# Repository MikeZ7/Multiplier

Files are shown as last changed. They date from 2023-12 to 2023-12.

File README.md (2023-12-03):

# Multiplier

Project of four quadrant multiplier for Systems and Electronics Circuits subject

---

## Project description
* Power Supply: (4V - 6V) DC
* Input signals range: (-1.5V - 1.5V) DC/AC
* PCB dimensions: 60x30mm 
* PCB components size: 0805
  
---

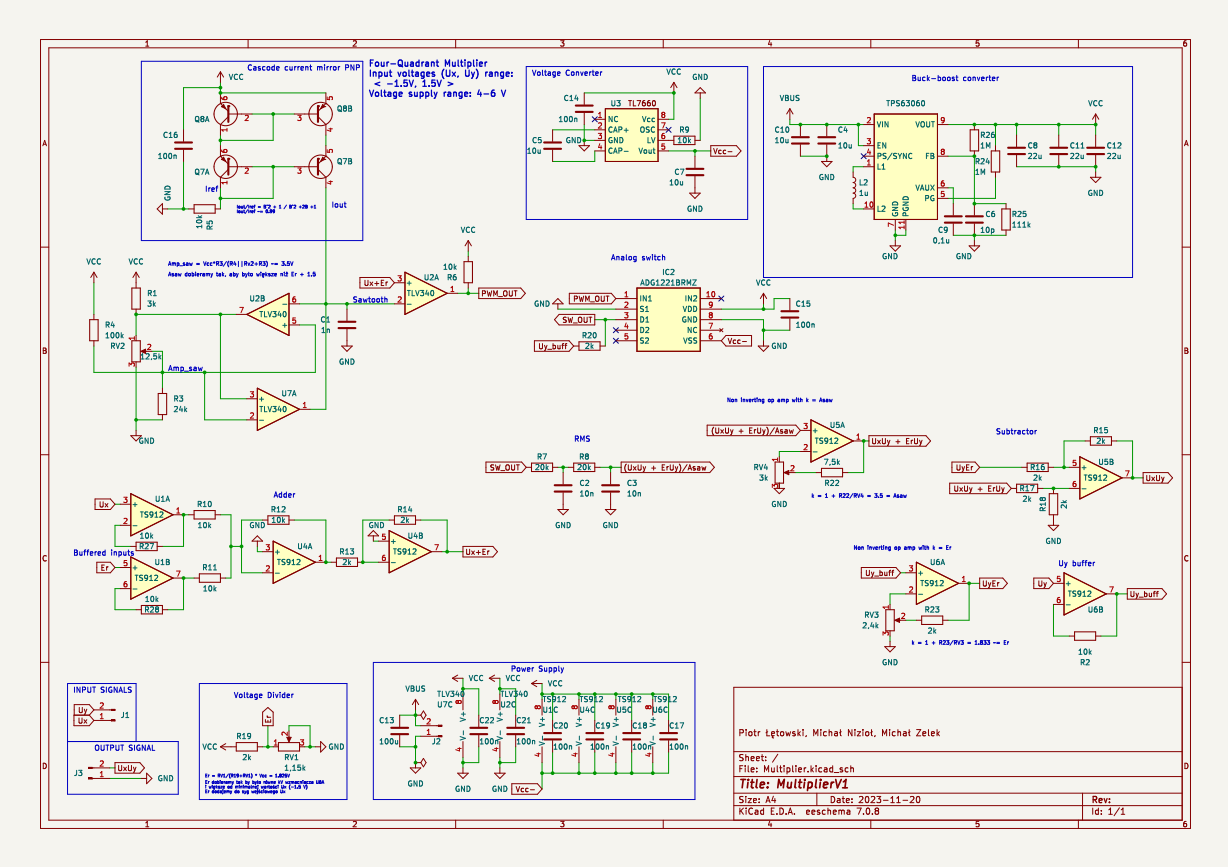
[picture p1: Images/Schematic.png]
Schematic


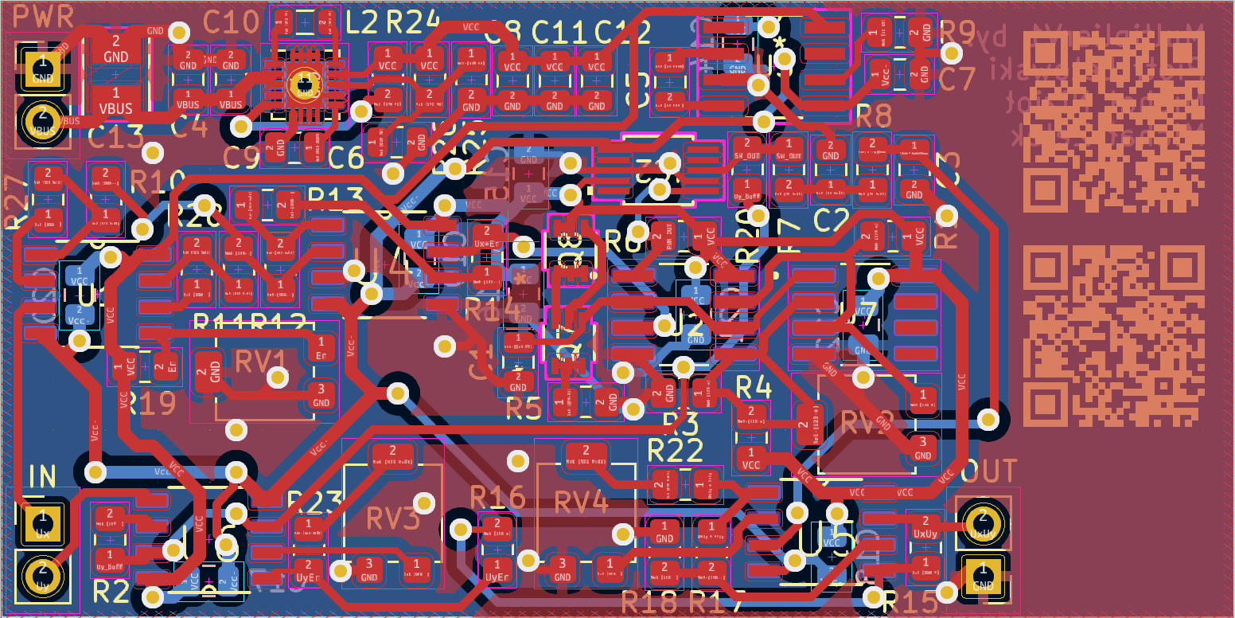
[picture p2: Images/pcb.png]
PCB


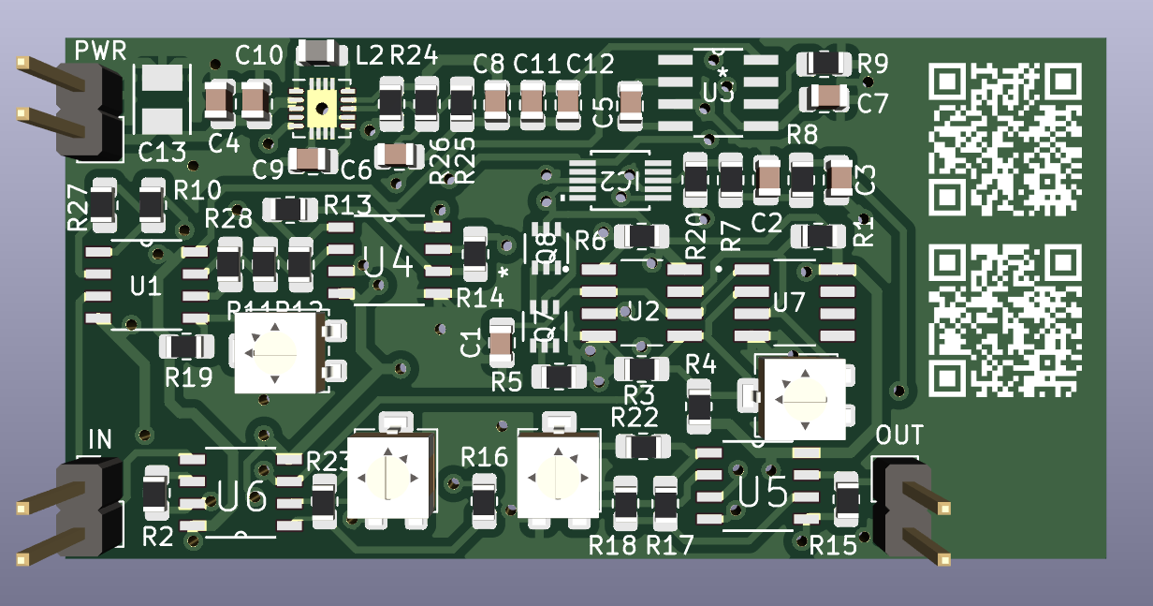
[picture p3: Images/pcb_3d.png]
3D


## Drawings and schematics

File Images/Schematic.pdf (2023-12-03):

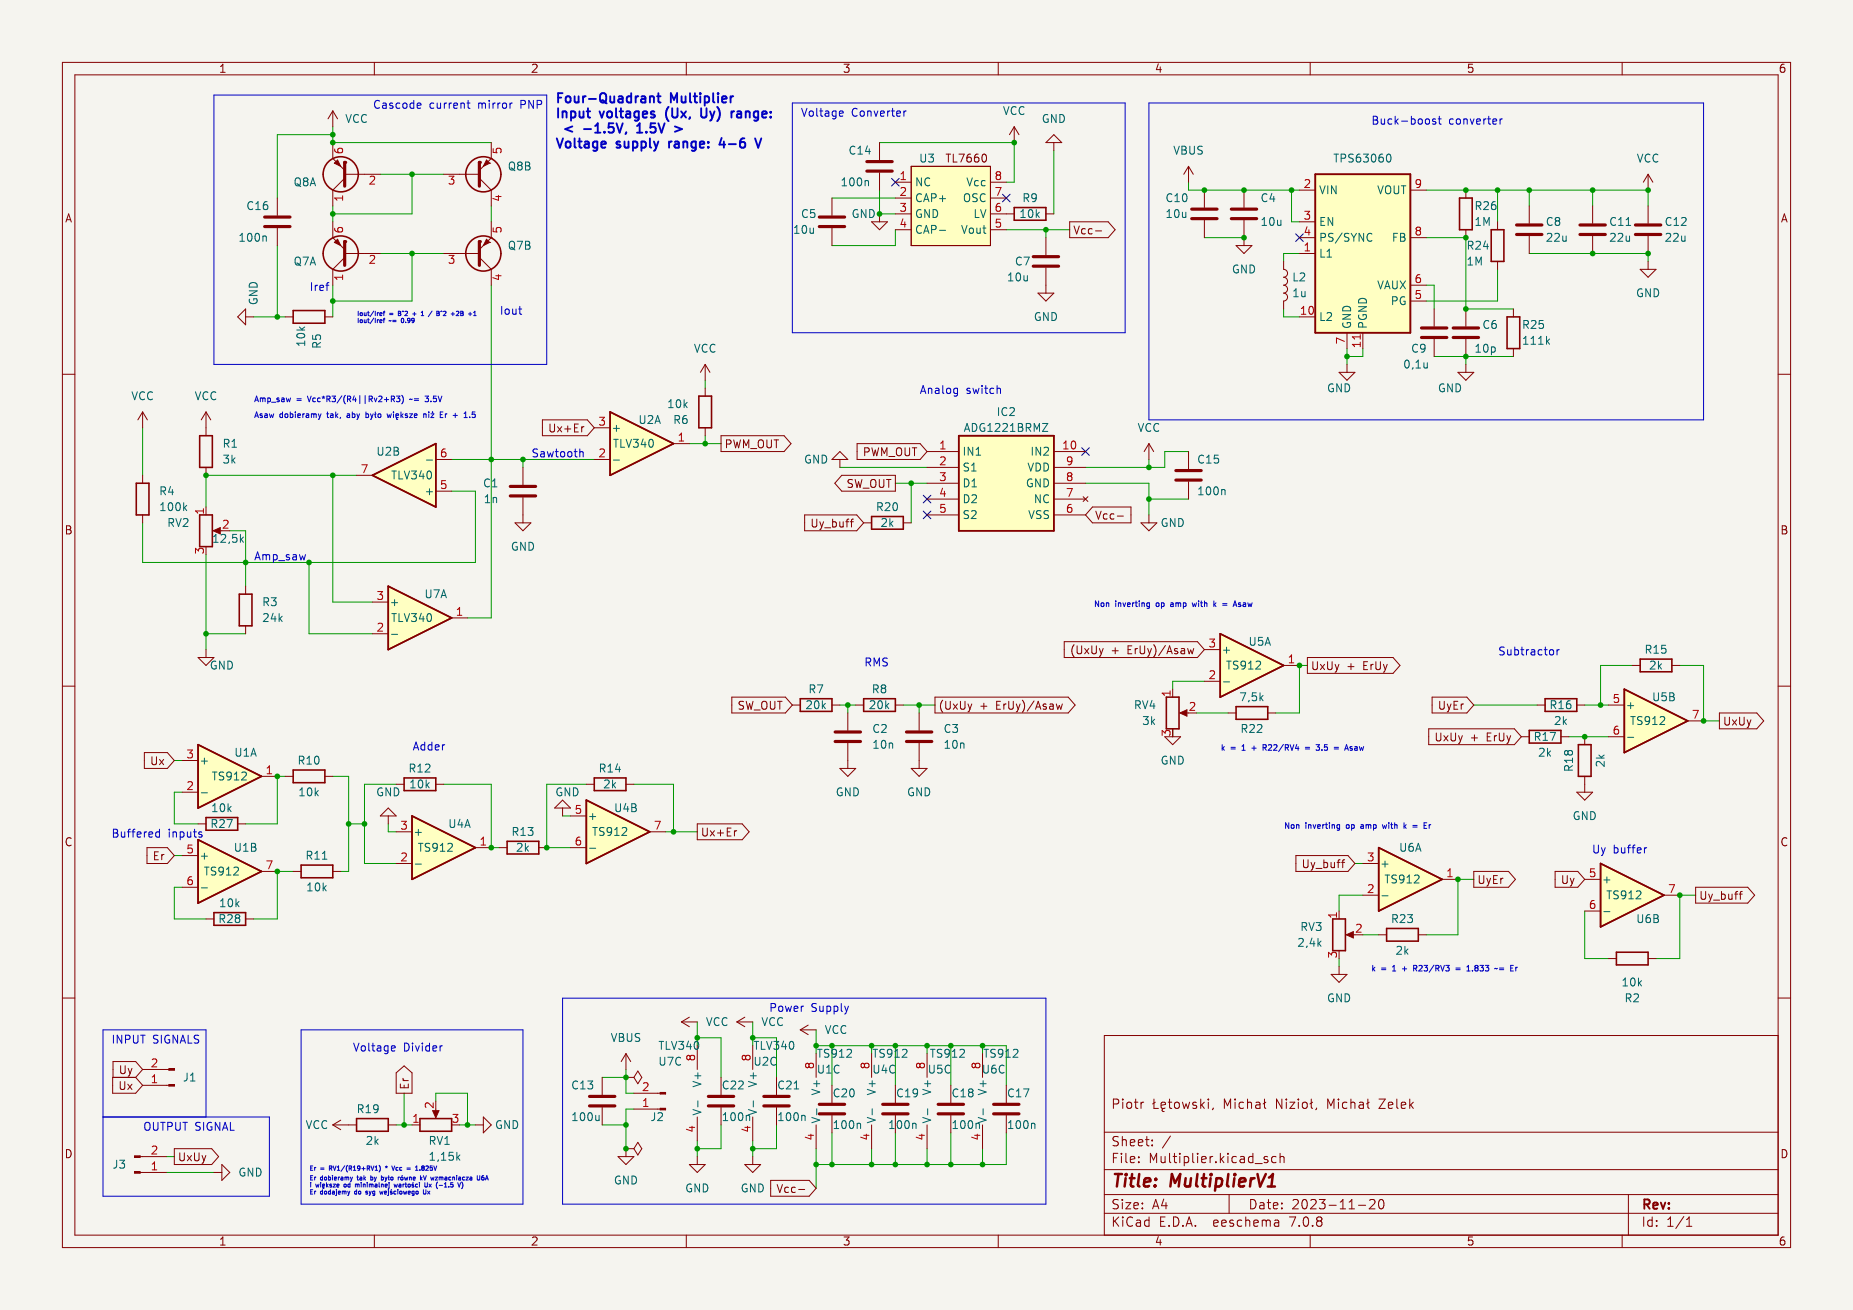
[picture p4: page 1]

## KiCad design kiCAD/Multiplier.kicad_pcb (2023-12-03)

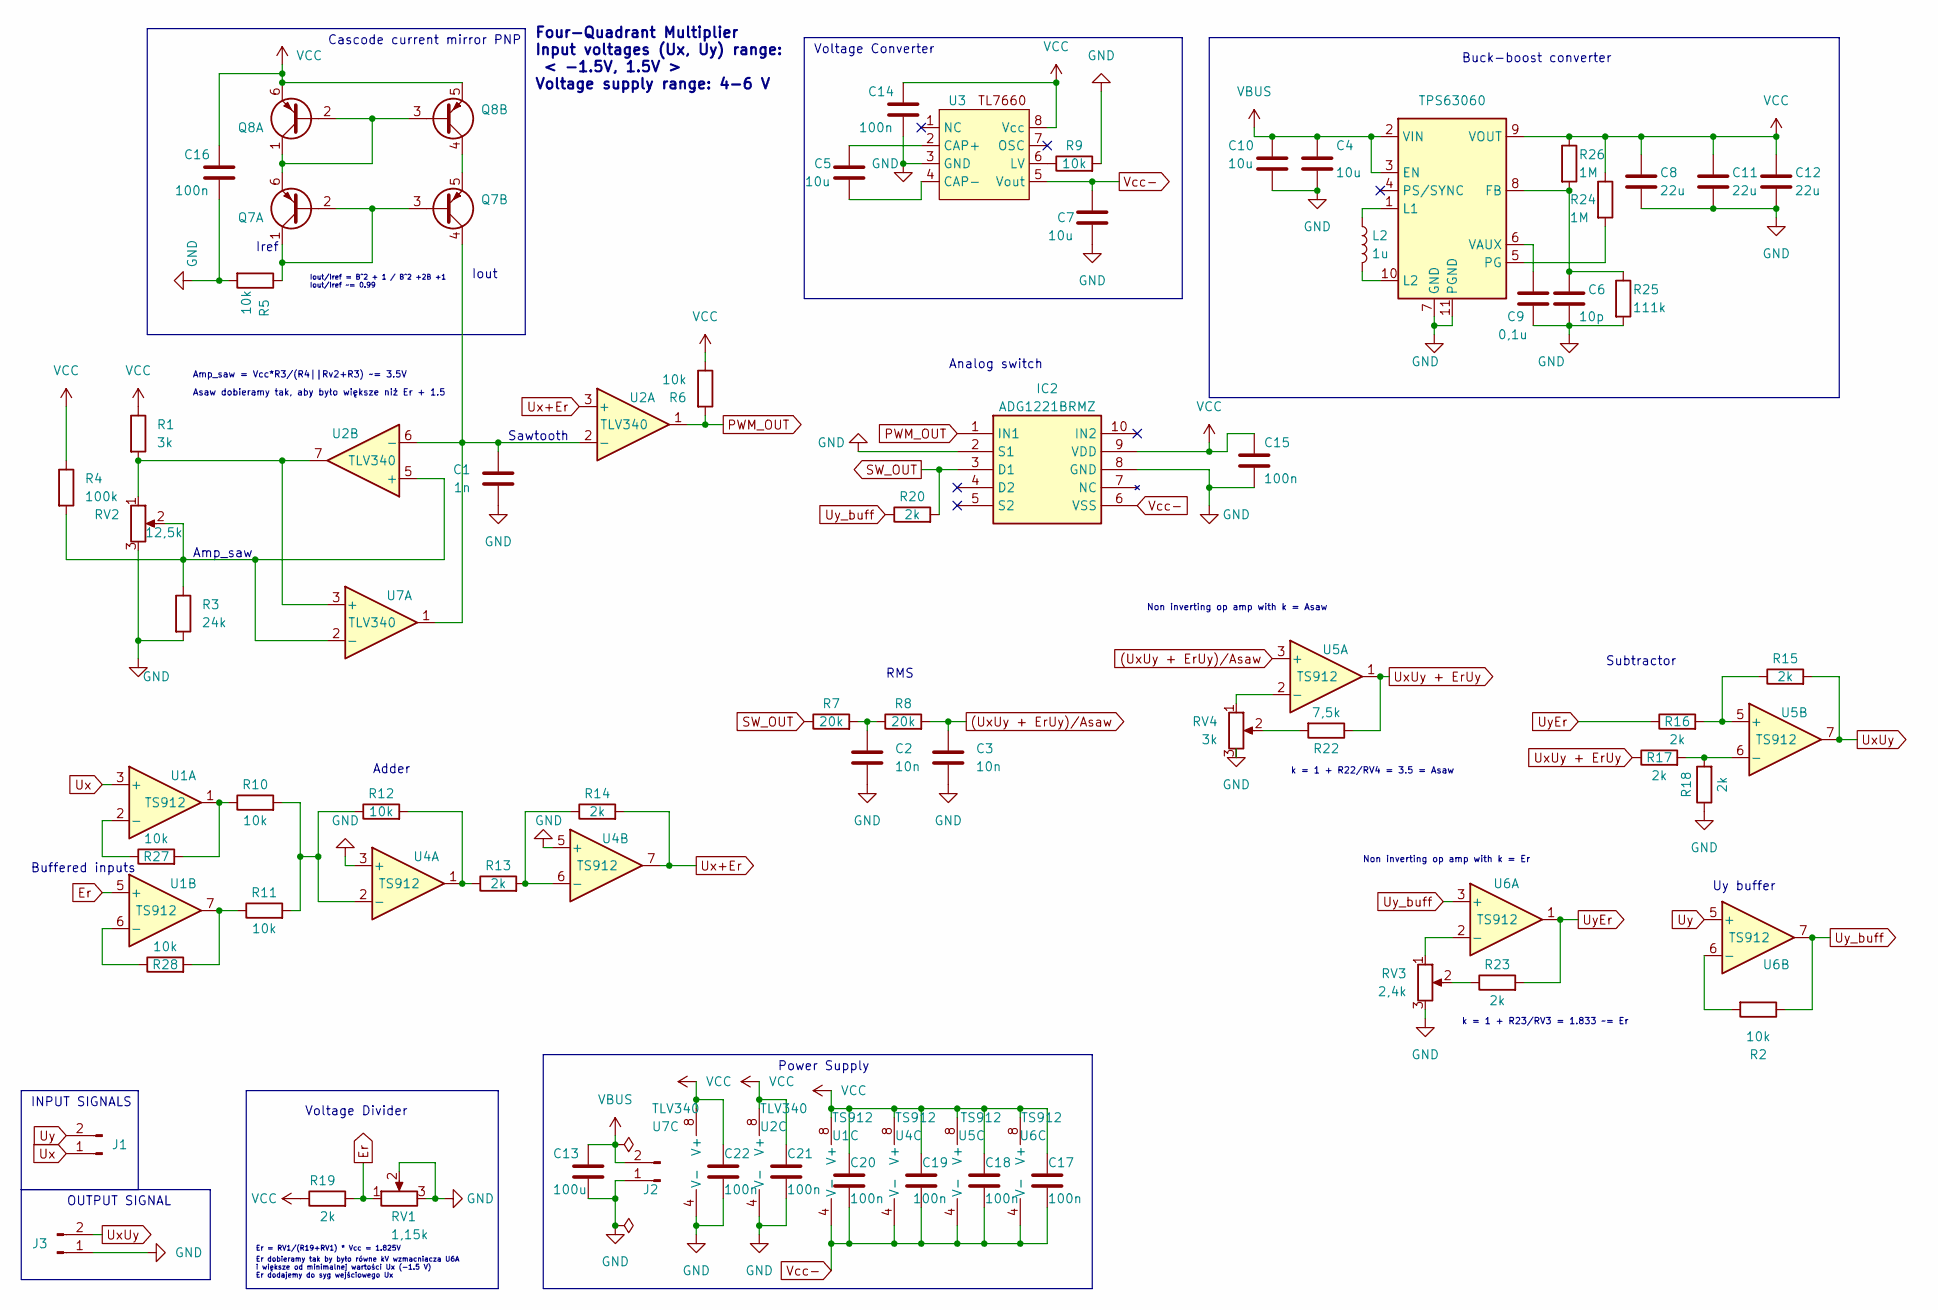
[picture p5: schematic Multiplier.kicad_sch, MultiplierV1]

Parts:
C1: 1n; C_0805_2012Metric
C2, C3: 10n; C_0805_2012Metric
C4, C5, C7, C10: 10u; C_0805_2012Metric
C6: 10p; C_0805_2012Metric
C8, C11, C12: 22u; C_0805_2012Metric
C9: 0,1u; C_0805_2012Metric
C13: 100u; CAP_293D-B_VSS
C14, C15, C16, C17, C18, C19, C20, C21, C22: 100n; C_0805_2012Metric
IC2: ADG1221BRMZ; RM_10_ADI; Mouser Part Number 584-ADG1221BRMZ
J1, J2, J3: Conn_01x02_Pin; PinHeader_1x02_P2.54mm_Vertical
L2: 1u; L_0805_2012Metric
Q7, Q8: Q_Dual_PNP_PNP_C1B1B2C2E2E1; SOT-363_DUAL_PNP
R1: 3k; R_0805_2012Metric_Pad1.20x1.40mm_HandSolder
R2, R5, R6, R9, R10, R11, R12, R27, R28: 10k; R_0805_2012Metric_Pad1.20x1.40mm_HandSolder
R3: 24k; R_0805_2012Metric_Pad1.20x1.40mm_HandSolder
R4: 100k; R_0805_2012Metric_Pad1.20x1.40mm_HandSolder
R7, R8: 20k; R_0805_2012Metric_Pad1.20x1.40mm_HandSolder
R13, R14, R15, R16, R17, R18, R19, R20, R23: 2k; R_0805_2012Metric_Pad1.20x1.40mm_HandSolder
R22: 7,5k; R_0805_2012Metric_Pad1.20x1.40mm_HandSolder
R24, R26: 1M; R_0805_2012Metric_Pad1.20x1.40mm_HandSolder
R25: 111k; R_0805_2012Metric_Pad1.20x1.40mm_HandSolder
RV1: 1,15k; Potentiometer_Bourns_3314G_Vertical
RV2: 12,5k; Potentiometer_Bourns_3314G_Vertical
RV3: 2,4k; Potentiometer_Bourns_3314G_Vertical
RV4: 3k; Potentiometer_Bourns_3314G_Vertical
U1, U4, U5, U6: TS912; TS912AIDT-SOIC8
U2, U7: TLV340; TLV3402IDR_SOIC8
U3: D8
U10: TPS63060; Texas_S-PWSON-N10_ThermalVias_Custom

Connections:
(UxUy + ErUy)/Asaw: C3.1, R8.2, U5.3 (+)
Er: R19.2, RV1.1, U1.5 (+)
GND: C1.2, C2.2, C3.2, C4.2, C6.2, C7.2, C8.2, C9.2, C10.2, C11.2, C12.2, C13.2, C14.2, C15.2, C16.2, C21.2, C22.2, IC2.2 (S1), IC2.8 (GND), J2.1, J3.1, R3.2, R5.2, R9.2, R18.1, R25.2, RV1.2, RV1.3, RV2.3, RV3.3, RV4.3, U2.4 (V-), U3.3 (GND), U4.3 (+), U4.5 (+), U7.4 (V-), U10.7 (GND), U10.11 (PGND); also elsewhere on the board
unnamed: C2.1, R7.2, R8.1
unnamed: Q7.1 (C1), Q7.2 (B1), Q7.3 (B2), R5.1
unnamed: Q7.6 (E1), Q8.1 (C1), Q8.2 (B1), Q8.3 (B2)
unnamed: C1.1, Q7.4 (C2), U2.2 (-), U2.6 (-), U7.1
unnamed: Q7.5 (E2), Q8.4 (C2)
unnamed: R10.1, R27.2, U1.1
unnamed: R11.1, R28.2, U1.7
unnamed: R12.2, R13.1, U4.1
unnamed: R22.2, RV4.2
unnamed: R23.1, RV3.2
unnamed: R27.1, U1.2 (-)
unnamed: R28.1, U1.6 (-)
unnamed: R3.1, R4.2, RV2.2, U2.5 (+), U7.2 (-)
unnamed: C5.1, U3.2 (CAP+)
unnamed: C5.2, U3.4 (CAP-)
unnamed: R9.1, U3.6 (LV)
unnamed: R10.2, R11.2, R12.1, U4.2 (-)
unnamed: R13.2, R14.1, U4.6 (-)
unnamed: RV4.1, U5.2 (-)
unnamed: R15.1, R16.2, U5.5 (+)
unnamed: R17.2, R18.2, U5.6 (-)
unnamed: RV3.1, U6.2 (-)
unnamed: R2.2, U6.6 (-)
unnamed: R1.2, RV2.1, U2.7, U7.3 (+)
unnamed: C6.1, R25.1, R26.2, U10.8 (FB)
unnamed: L2.1, U10.1 (L1)
unnamed: L2.2, U10.10 (L2)
unnamed: R24.2, U10.5 (PG)
unnamed: C9.1, U10.6 (VAUX)
PWM_OUT: IC2.1 (IN1), R6.2, U2.1
SW_OUT: IC2.3 (D1), R7.1, R20.2
Ux: J1.1, U1.3 (+); also elsewhere on the board
Ux+Er: R14.2, U2.3 (+), U4.7
UxUy: J3.2, R15.2, U5.7; also elsewhere on the board
UxUy + ErUy: R17.1, R22.1, U5.1
Uy: J1.2, U6.5 (+); also elsewhere on the board
UyEr: R16.1, R23.2, U6.1
Uy_buff: R2.1, R20.1, U6.3 (+), U6.7
VBUS: C4.1, C10.1, C13.1, J2.2, U10.2 (VIN), U10.3 (EN); also elsewhere on the board
VCC: C8.1, C11.1, C12.1, C14.1, C15.1, C16.1, C17.1, C18.1, C19.1, C20.1, C21.1, C22.1, IC2.9 (VDD), Q8.5 (E2), Q8.6 (E1), R1.1, R4.1, R6.1, R19.1, R24.1, R26.1, U1.8 (V+), U2.8 (V+), U3.8 (Vcc), U4.8 (V+), U5.8 (V+), U6.8 (V+), U7.8 (V+), U10.9 (VOUT)
Vcc-: C7.1, C17.2, C18.2, C19.2, C20.2, IC2.6 (VSS), U1.4 (V-), U3.5 (Vout), U4.4 (V-), U5.4 (V-), U6.4 (V-)

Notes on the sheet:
Non inverting op amp with k = Er
Cascode current mirror PNP
Iref
Analog switch
Iout
Iout/Iref = B^2 + 1 / B^2 +2B +1
OUTPUT SIGNAL
Non inverting op amp with k = Asaw
Buffered inputs
RMS
Amp_saw
Four-Quadrant Multiplier Input voltages (Ux, Uy) range: < -1.5V, 1.5V > Voltage supply range: 4-6 V
Er dobieramy tak by było równe kV wzmacniacza U6A i większe od minimalnej wartości Ux (-1.5 V) Er dodajemy do syg wejściowego Ux
Uy buffer
Adder
Asaw dobieramy tak, aby było większe niż Er + 1.5
INPUT SIGNALS
Er = RV1/(R19+RV1) * Vcc = 1.825V
Sawtooth
Subtractor
k = 1 + R22/RV4 = 3.5 = Asaw
Iout/Iref ~= 0.99
Power Supply
k = 1 + R23/RV3 = 1.833 ~= Er
Buck-boost converter
Voltage Divider
Amp_saw = Vcc*R3/(R4||Rv2+R3) ~= 3.5V
Voltage Converter

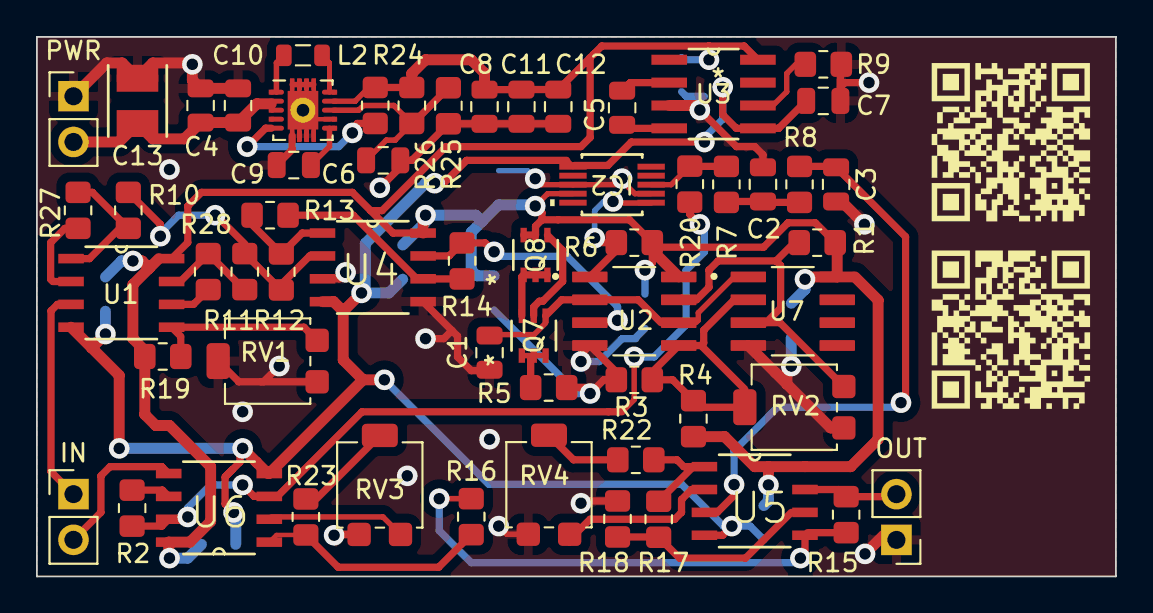
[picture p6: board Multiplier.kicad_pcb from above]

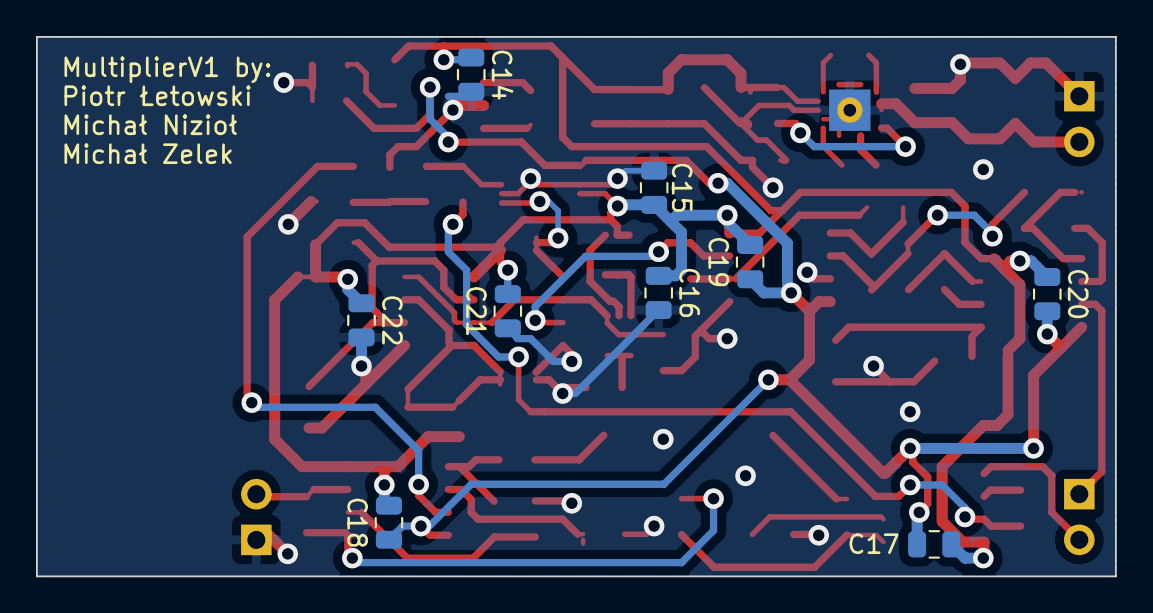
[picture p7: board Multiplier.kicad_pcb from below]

Board: 2 copper layers, 59.9 x 30.0 mm, 68 parts (9 on the bottom side), 44 nets.

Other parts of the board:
IN: Conn_01x02_Pin; PinHeader_1x02_P2.54mm_Vertical
OUT: Conn_01x02_Pin; PinHeader_1x02_P2.54mm_Vertical
PWR: Conn_01x02_Pin; PinHeader_1x02_P2.54mm_Vertical

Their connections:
GND: OUT.1, PWR.1; also elsewhere on the board
Ux: IN.1; also elsewhere on the board
UxUy: OUT.2; also elsewhere on the board
Uy: IN.2; also elsewhere on the board
VBUS: PWR.2; also elsewhere on the board

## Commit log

2023-11-21 Uploading the first version of Kicad project
    [Multiplier.kicad_pcb, Multiplier.kicad_sch]
2023-11-22 Adding image of multiplier schematics
2023-11-22 Update README.md
    Add schematics image
2023-11-22 Adding image of schematics
2023-11-22 Add Images and kiCAD directories to clean the mess
2023-11-24 Replacing schematics for TLV3402IDR assigning footpritns and adding first PCB layout
    [Multiplier.kicad_pcb, Multiplier.kicad_sch]
2023-11-24 adding potentiometer
    [Multiplier.kicad_sch]
2023-11-24 Modified: Multiplier.kicad_sch (resistors values)
    [Multiplier.kicad_sch]
2023-11-29 New footprint for buck-boost converter
    [Multiplier.kicad_pcb, Multiplier.kicad_sch]
2023-11-29 Initial routing and layout
    [Multiplier.kicad_pcb, Multiplier.kicad_sch]
2023-11-30 First PCB design with GND fields and tantalum (100nF) coupling capacitor added
    [Multiplier.kicad_pcb, Multiplier.kicad_sch]
2023-11-30 New footprint for TSP and tantalum capacitor
    [Multiplier.kicad_sch]
2023-11-30 Add tantalum cap footprint
    [Multiplier.kicad_pcb]
2023-11-30 Finished first PCB prototype
    [Multiplier.kicad_pcb]
2023-12-03 New schematic image, final PCB design
    [Multiplier.kicad_pcb, Multiplier.kicad_sch]
2023-12-03 Reloading branch
    [Multiplier.kicad_pcb, Multiplier.kicad_sch]
2023-12-03 Revert "Reloading branch"
    This reverts commit 17a884d624d71886552ad5c8232560fd1f52b29e.
    [Multiplier.kicad_pcb, Multiplier.kicad_sch]
2023-12-03 Final PCB version
    [Multiplier.kicad_pcb, Multiplier.kicad_sch]
2023-12-03 Uploading images of PCB view
